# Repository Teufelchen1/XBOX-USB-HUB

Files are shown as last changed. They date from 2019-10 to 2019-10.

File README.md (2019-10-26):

# XBOX-USB-HUB
Collection of information and homemade schematics of the XBOX Rev 1.0 USB PCB

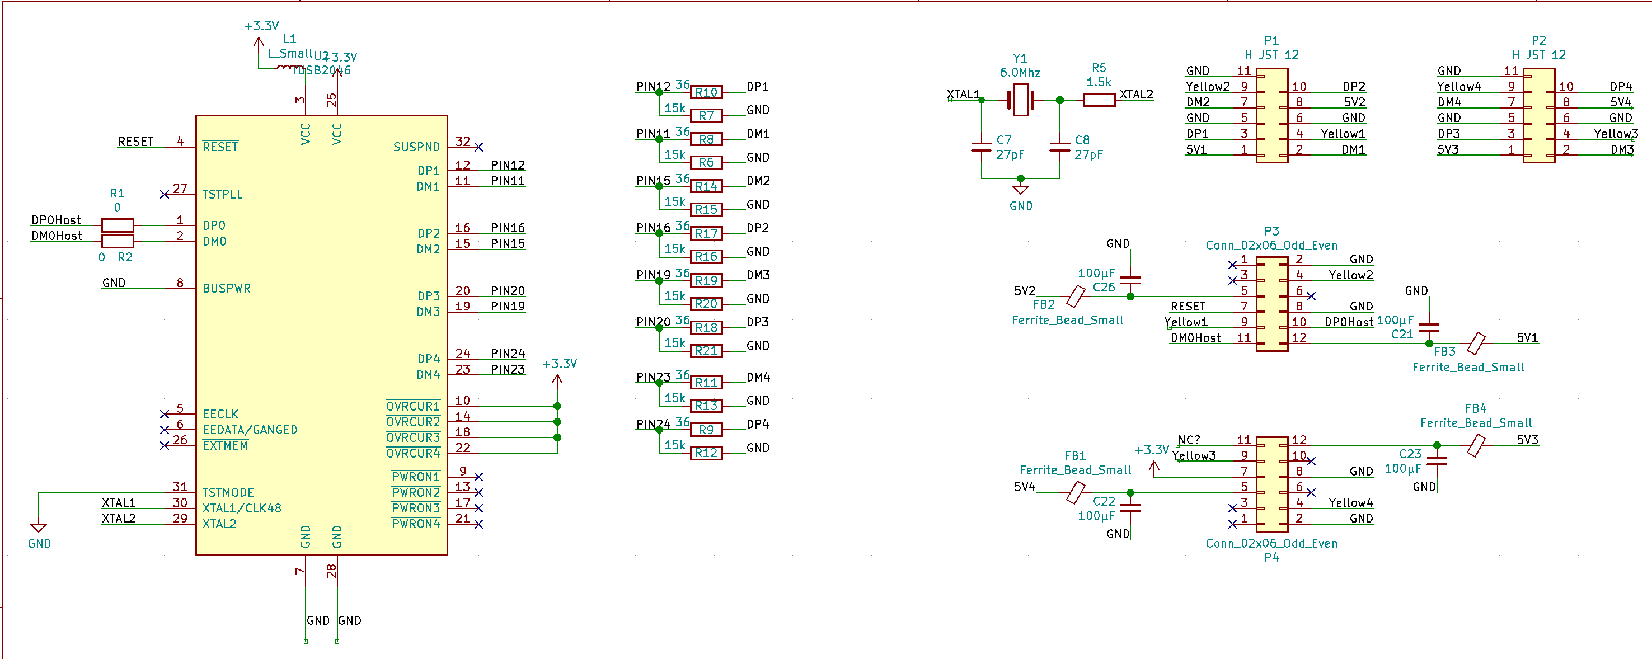
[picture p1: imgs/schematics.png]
Schematics


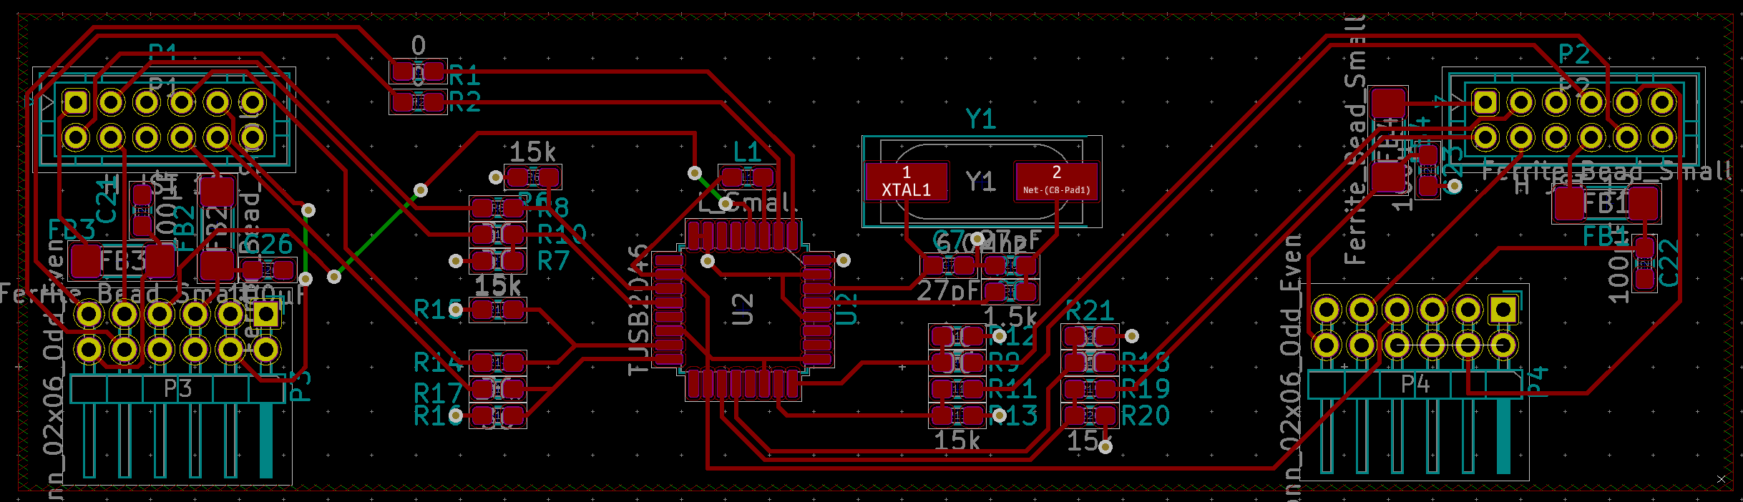
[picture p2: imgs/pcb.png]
PCB


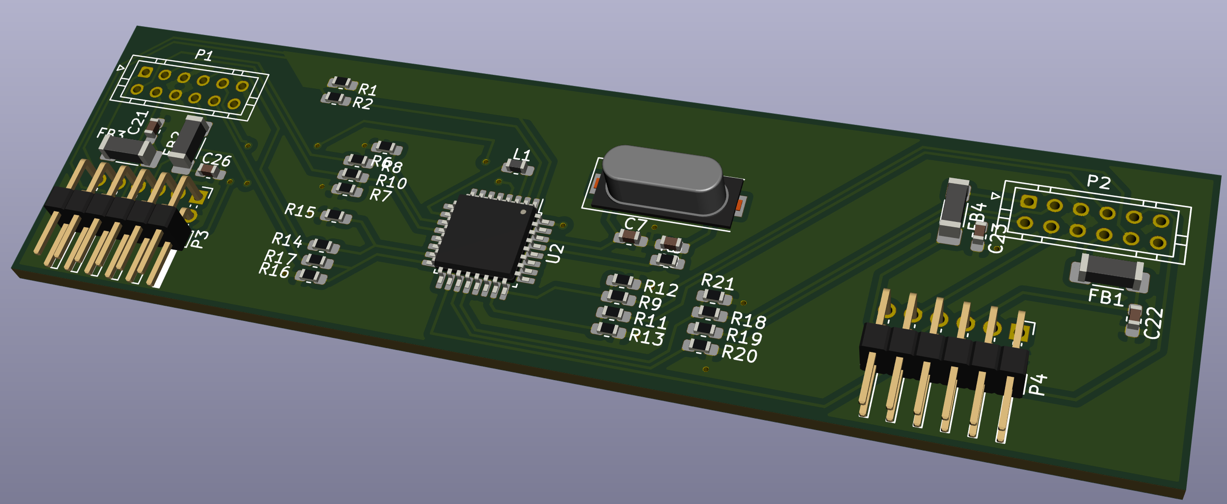
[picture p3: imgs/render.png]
Render


| Label  |Value |CLabel |State |Function|
|---|---|---|---|---|
|R1|0|R1|Ok|In series DM0|
|R2|0|R2|Ok|In series DP0|
|R3|700|R3|Value guessed|Pull-up DP0|
|R4|||Unkown||
|R5|1.5k|R5|Value from DS|between IC & crystal|
|R6|15k|R6|Value guessed|Pull-down DM1|
|R7|15k|R7|Value guessed|Pull-down DP1|
|R8|36|R8|Value guessed|Termination of DM1|
|R9|36|R9|Value guessed|Termination of DP4|
|R10|36|R10|Value guessed|Termination of DP1|
|R11|35|R11|Value guessed|Termination of DM4|
|R12|15k|R12|Value guessed|Pull-down DP4|
|R13|15k|R13|Value guessed|Pull-down DM4|
|R14|36|R14|Value guessed|Termination of DM2|
|R15|15k|R15|Value guessed|Pull-down DM2|
|R16|15k|R16|Value guessed|Pull-down DP2|
|R17|36|R17|Value guessed|Termination of DP2|
|R18|36|R18|Value guessed|Termination of DP3|
|R19|36|R19|Value guessed|Termination of DM3|
|R20|15k|R20|Value guessed|Pull-down DM3|
|R21|15k|R21|Value guessed|Pull-down DP3|
|C21||C21|intended|Stability 5V-GND controler 3/4|
|C26||C26|intended|Stability 5V-GND controler 3/4|
|C4|||Unpopulated||
|C3|||Unpopulated||
|C6|||Unpopulated||
|C9|||Unpopulated||
|C10|||Unpopulated||
|C14|||Unpopulated||
|C15|||Unpopulated||
|C18|||Missing|Stability 3.3V-GND|
|C5|||Missing|Stability 3.3V-GND|
|C2|||Missing|Stability 3.3V-GND|
|C19|||Missing|Stability 3.3V-GND|
|C20|||Missing|Stability 3.3V-GND|
|C7|27pF|C7|Value from DS|crystal|
|C8|27pF|C8|Value from DS|crystal|
|C24|||Missing|GND-C24-L3-3.3V|
|C25|||Missing|GND-C25-L3-3.3V|
|C11|||Missing|GND-C11-3.3V|
|C12|||Unpopulated||
|C13|||Unpopulated||
|C16|||Unpopulated||
|C17|||Unpopulated||
|C23||C23|intended|Stability 5V-GND controler 1/2|
|C22||C22|intended|Stability 5V-GND controler 1/2|
|C27|||Missing||
|L7||L7|intended|In series 5V|
|L8||L8|intended|In series 5V|
|L2|||Missing|Common mode chokes|
|L6|||Missing|Common mode chokes|
|L1|||Missing||
|L9|||Missing|Common mode chokes|
|L10|||Missing|Common mode chokes|
|L4||L4|intended|In series 5V|
|L5||L5|intended|In series 5V|
|P1|H JST 12|P1|Ok|Controler 3 & 4|
|P3|2x6 male|P3|Ok|Host USB, Yellow 1 & 2|
|P2|H JST 12|P2|Ok|Controler 1 & 2|
|P4|2x6 male|P4|Ok|Yellow 3 & 4|
|Y1|6MHz|Y1|Ok|crystal|
|U2|TUSB2046B|U2|Ok|Main IC|

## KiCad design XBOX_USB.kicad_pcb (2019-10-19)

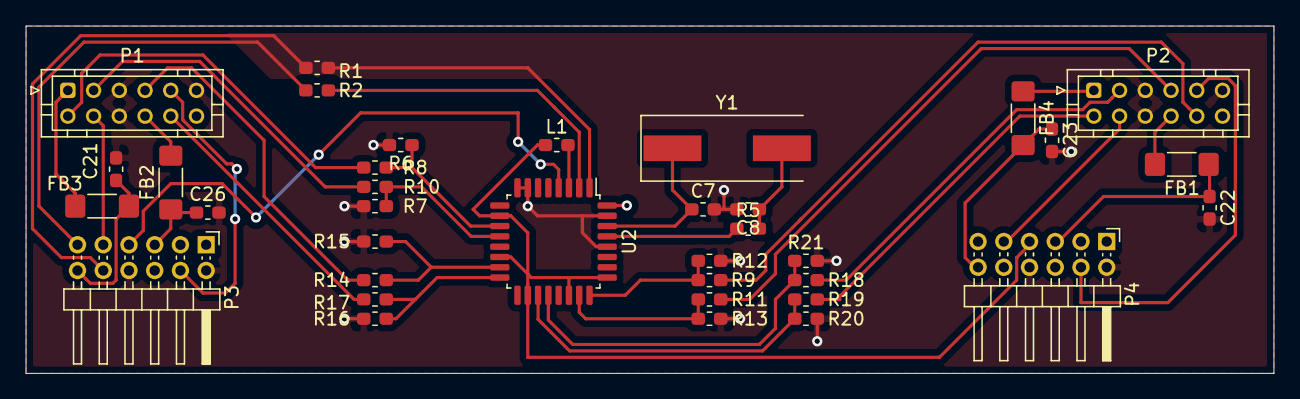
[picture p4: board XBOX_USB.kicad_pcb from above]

Board: 2 copper layers, 97.0 x 27.0 mm, 36 parts (0 on the bottom side), 39 nets.

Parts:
C7, C8: 27pF; C_0603_1608Metric_Pad1.05x0.95mm_HandSolder
C21, C22, C23, C26: 100µF; C_0603_1608Metric_Pad1.05x0.95mm_HandSolder
FB1, FB2, FB3, FB4: Ferrite_Bead_Small; L_1806_4516Metric_Pad1.57x1.80mm_HandSolder
L1: L_Small; L_0603_1608Metric_Pad1.05x0.95mm_HandSolder
P1, P2: H JST 12; JST_PHD_B12B-PHDSS_2x06_P2.00mm_Vertical
P3, P4: Conn_02x06_Odd_Even; PinHeader_2x06_P2.00mm_Horizontal
R1, R2: 0; R_0603_1608Metric_Pad1.05x0.95mm_HandSolder
R5: 1.5k; R_0603_1608Metric_Pad1.05x0.95mm_HandSolder
R6, R7, R12, R13, R15, R16, R20, R21: 15k; R_0603_1608Metric_Pad1.05x0.95mm_HandSolder
R8, R9, R10, R11, R14, R17, R18, R19: 36; R_0603_1608Metric_Pad1.05x0.95mm_HandSolder
U2: TUSB2046; LQFP-32_7x7mm_P0.8mm
Y1: 6.0Mhz; Crystal_SMD_HC49-SD

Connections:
+3V3: L1.1, P4.7, U2.10, U2.14, U2.18, U2.22, U2.25
/5V1: FB3.1, P1.1
/5V2: FB2.2, P1.8
/5V3: FB4.1, P2.1
/5V4: FB1.2, P2.8
/DM0Host: P3.11, R2.2
/DM1: P1.2, R8.1
/DM2: P1.7, R14.1
/DM3: P2.2, R19.1
/DM4: P2.7, R11.1
/DP0Host: P3.10, R1.2
/DP1: P1.3, R10.1
/DP2: P1.10, R17.1
/DP3: P2.3, R18.1
/DP4: P2.10, R9.1
/PIN11: R6.1, R8.2, U2.11
/PIN12: R7.2, R10.2, U2.12
/PIN15: R14.2, R15.1, U2.15
/PIN16: R16.1, R17.2, U2.16
/PIN19: R19.2, R20.1, U2.19
/PIN20: R18.2, R21.1, U2.20
/PIN23: R11.2, R13.1, U2.23
/PIN24: R9.2, R12.1, U2.24
/RESET: P3.7, U2.4
/XTAL1: C7.1, U2.30, Y1.1
/XTAL2: R5.1, U2.29
/Yellow1: P1.4, P3.9
/Yellow2: P1.9, P3.4
/Yellow3: P2.4, P4.9
/Yellow4: P2.9, P4.4
GND: C7.2, C8.2, C21.2, C22.2, C23.2, C26.2, P1.5, P1.6, P1.11, P2.5, P2.6, P2.11, P3.2, P3.8, P4.2, P4.8, R6.2, R7.1, R12.2, R13.2, R15.2, R16.2, R20.2, R21.2, U2.7, U2.8, U2.28, U2.31
unnamed: C8.1, R5.2, Y1.2
unnamed: C21.1, FB3.2, P3.12
unnamed: C22.1, FB1.1, P4.5
unnamed: C23.1, FB4.2, P4.12
unnamed: C26.1, FB2.1, P3.5
unnamed: L1.2, U2.3
unnamed: R1.1, U2.1
unnamed: R2.1, U2.2

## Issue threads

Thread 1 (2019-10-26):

Dimensions of the PCB

Teufelchen1, 2019-10-26:
The placement of the components and the shape of the PCB still have to be verified. Especially the connectors P3 & P4 must be correct positioned to suit onto the xbox mainboard.

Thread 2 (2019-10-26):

Verify and measure resistors, caps and coils

Teufelchen1, 2019-10-26:
Almost all values are either missing or are guessed.
To correctly measure them, they have to be unsoldered. (which is a lot of work :/).
Most guessed values are quite accurate since their purpose is clear, they are suggested by some data sheets and some can be probed by an multimeter.

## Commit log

2019-10-19 adding KiCad images
2019-10-26 doc(readme): adding connector names to list
